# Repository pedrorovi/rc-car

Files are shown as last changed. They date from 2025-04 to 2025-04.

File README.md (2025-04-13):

# RC Car Project

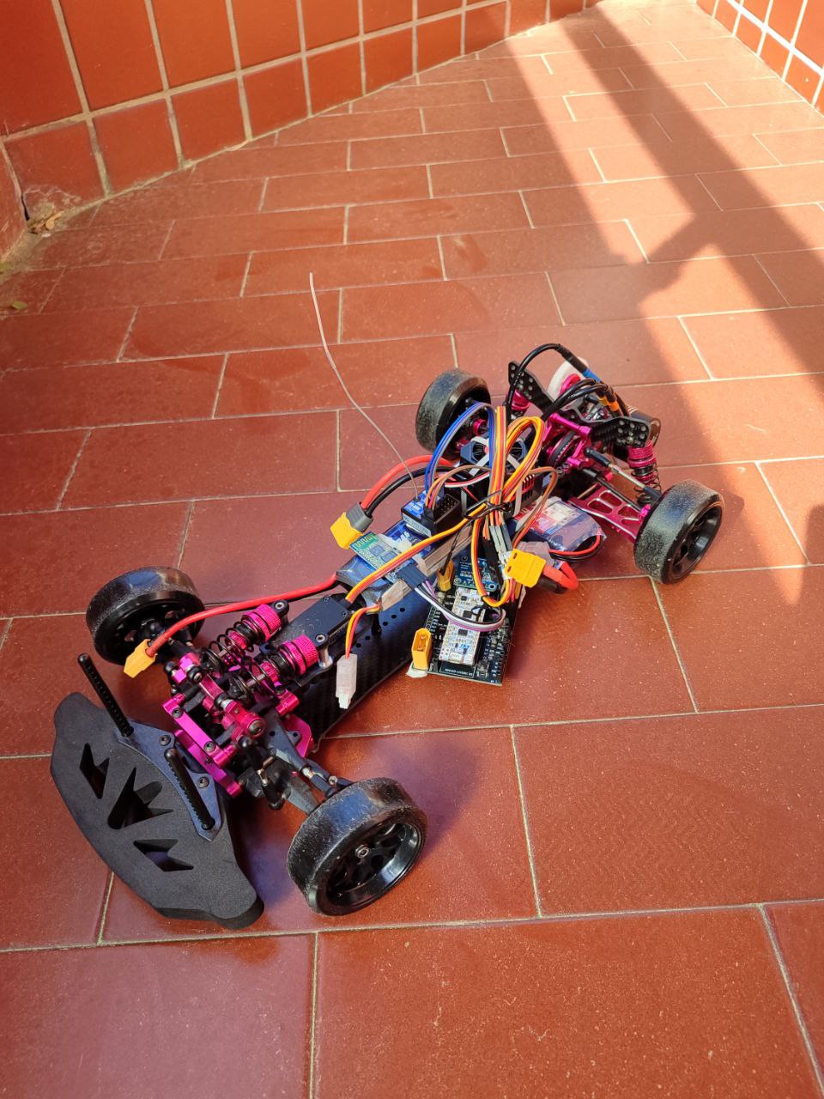
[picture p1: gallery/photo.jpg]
RC Car

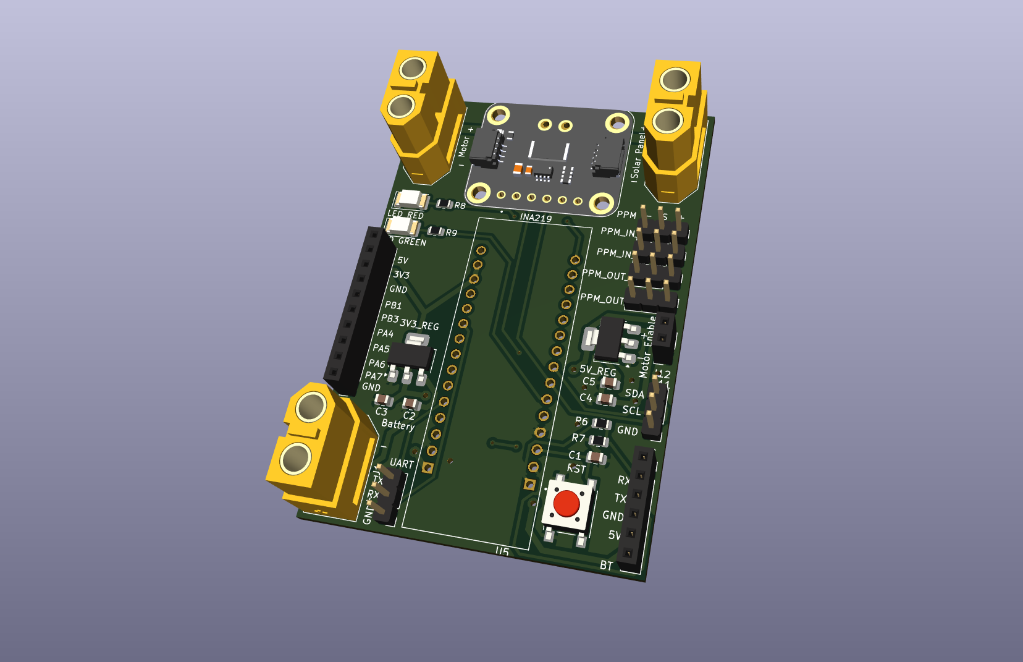
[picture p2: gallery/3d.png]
PCB


This repository contains all the necessary files and resources to design, configure, and develop an RC car. The project is organized into three main folders:

## Folder Structure

### 1. `kicad/` - Hardware Design

This folder contains the hardware design files for the RC car, created using KiCad. It includes:

- PCB layout files (`.kicad_pcb`)
- Schematic files (`.kicad_sch`)
- Gerber files for manufacturing
- Drill files and reports

### 2. `stm32-cube-ide/` - STM32L432KC Configuration

This folder contains the configuration files for the STM32L432KC microcontroller, set up using STM32CubeIDE. It includes:

- Peripheral initialization
- Clock configuration
- Pin assignments

### 3. `platformio/` - Firmware Development

This folder contains the firmware source code for the RC car, developed using PlatformIO. It includes:

- Source code for motor control, sensors, and communication
- Configuration files for PlatformIO
- Unit tests for firmware components

## Getting Started

### Prerequisites

- [KiCad](https://kicad.org/) for hardware design
- [STM32CubeIDE](https://www.st.com/en/development-tools/stm32cubeide.html) for microcontroller configuration
- [PlatformIO](https://platformio.org/) for firmware development

### Steps to Build the RC Car

1. **Hardware Design**: Open the `kicad/` folder in KiCad to view and modify the PCB and schematic designs. Generate Gerber files for manufacturing.
2. **Microcontroller Configuration**: Open the `stm32-cube-ide/` folder in STM32CubeIDE to configure the STM32L432KC microcontroller.
3. **Firmware Development**: Use PlatformIO to write and upload firmware to the microcontroller. Navigate to the `platformio/` folder and run:

   ```sh
   make build_embedded

## Shopping list

### Nucleo

[STM32L432KC](https://www.digikey.es/es/products/detail/stmicroelectronics/NUCLEO-L432KC/6132763)

### Radio

[Goolsky Flysky FS-GT5 2.4G 6CH Transmitter Remote Controller with FS-BS6 Receiver for RC Car Crawler Boat](https://a.co/d/gxiTpZ9)

### Car

[AXSPEED-Kit](https://es.aliexpress.com/item/1005004083219971.html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)

### Motor

[Rocket-Motor](https://es.aliexpress.com/item/1005003152797506.html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)

### Servo

[INJORA-Servo Digital](https://es.aliexpress.com/item/1005005066982557.html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)

### Batteries

[Zeee 2S Lipo Batería 50C 2200mAh 7.4V Batería Corta con Enchufe XT60](https://amzn.eu/d/79buMsG)

[Motor Battery](https://es.aliexpress.com/item/1005004770752418.html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)

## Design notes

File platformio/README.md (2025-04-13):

# RC Solar Car - STM32L432KC

This project is an embedded software application for controlling an RC solar-powered car using the STM32L432KC microcontroller. It includes various modules for hardware abstraction, motor control, power monitoring, and communication.

## Project Structure

. ├── .clang-format # Code formatting configuration ├── .gitignore # Git ignore rules ├── Makefile # Build system configuration ├── platformio.ini # PlatformIO project configuration ├── include/ # Header files for the project ├── lib/ # Libraries for hardware abstraction and drivers │ ├── FreeRTOS/ # FreeRTOS kernel source │ ├── hal/ # Hardware Abstraction Layer │ ├── motor_controller/ # Motor control logic │ ├── ina219/ # INA219 power sensor driver │ ├── debug/ # Debugging utilities │ └── ... # Other libraries ├── src/ # Application source code │ └── main.cpp # Main application entry point ├── test/ # Unit tests for the project └── README.md # Project documentation

## Features

- **Motor Control**: Includes modules for controlling DC and servo motors.
- **Power Monitoring**: Uses the INA219 sensor to measure current and voltage.
- **FreeRTOS Integration**: Real-time operating system for task scheduling.
- **Debugging Utilities**: Provides logging and debugging support.
- **Hardware Abstraction**: Simplifies interaction with peripherals like GPIO, I2C, and UART.

## Getting Started

### Prerequisites

- [PlatformIO](https://platformio.org/) installed on your system.
- STM32L432KC microcontroller development board.
- INA219 power sensor module.
- Motor drivers and motors.

### Building the Project

1. Build the project using PlatformIO:

```bash
make build_embedded
```

Upload the firmware to the STM32L432KC board:

```bash
make flash_embedded
```

Running Unit Tests
To run unit tests, use the PlatformIO Test Runner:

```bash
make test_*
```

License
This project includes components licensed under various open-source licenses:

The STM32 HAL driver is licensed under the BSD 3-Clause License.
The CMSIS library is licensed under the Apache License 2.0.
FreeRTOS is licensed under the MIT License.
Refer to the respective License.md files in the project for more details.

Contributing
Contributions are welcome! Please follow the coding style defined in the .clang-format file and ensure all tests pass before submitting a pull request.

Acknowledgments
STMicroelectronics for the STM32 HAL and CMSIS libraries.
Adafruit for the INA219 driver.
PlatformIO for the development environment.
For more information, refer to the documentation in the source code and the PlatformIO documentation. ```

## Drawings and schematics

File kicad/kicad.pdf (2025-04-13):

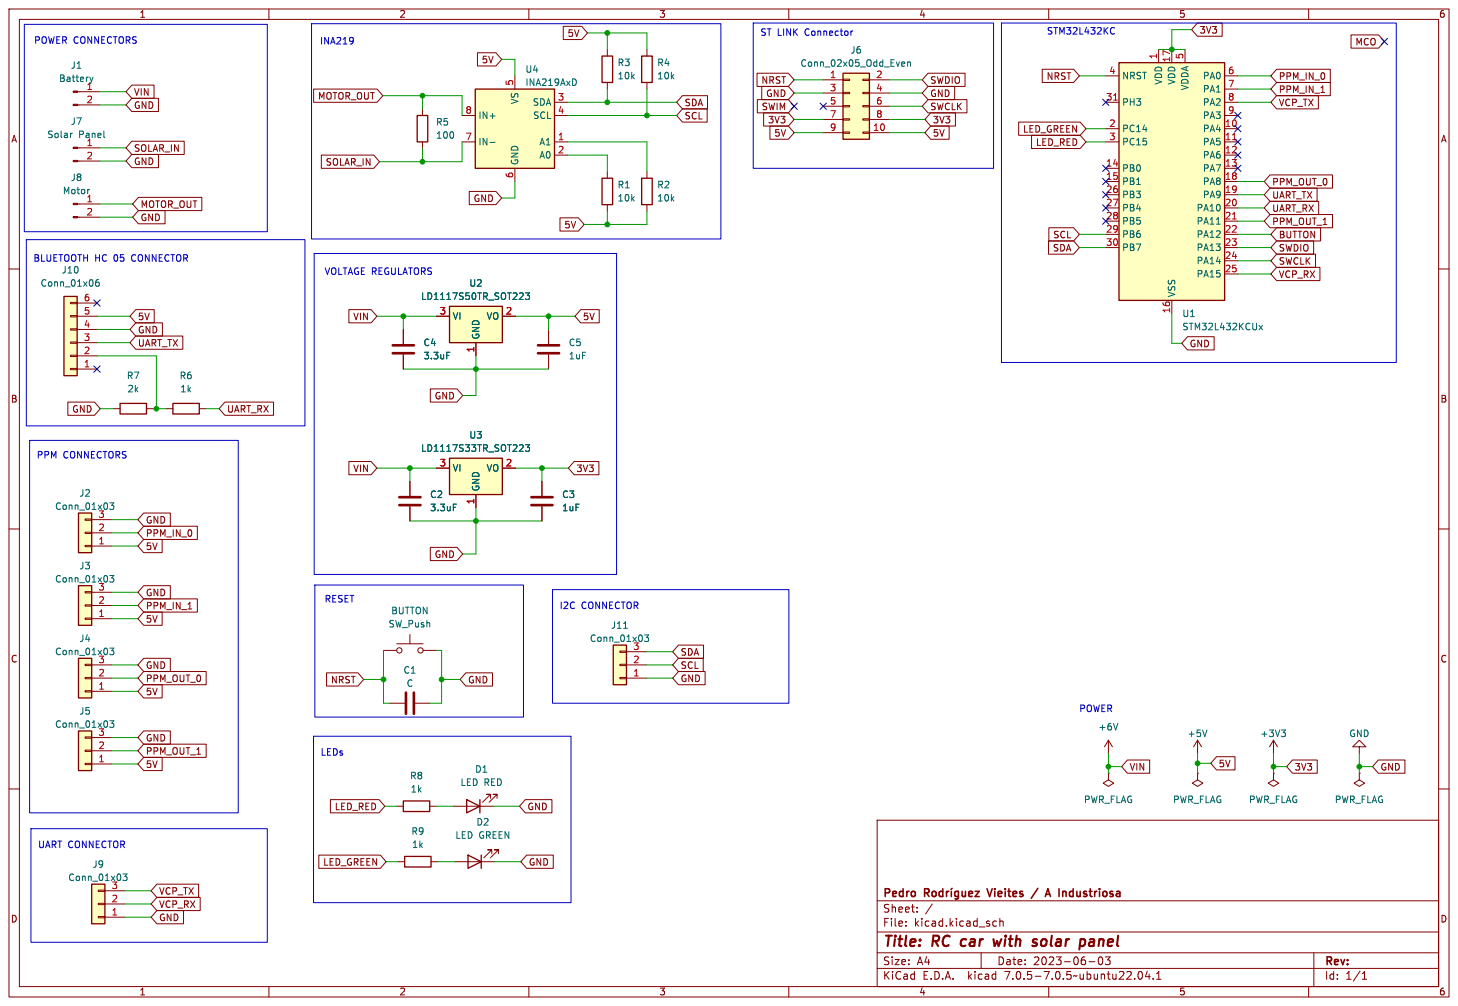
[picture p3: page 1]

1 PA4 10 PA5 11 PA6 12 PA7 13 PB0 14 PB1 15 VSS 16 VDD 17 PA8 18 PA9 19 PC14 2 PA10 20 PA11 21 PA12 22 PA13 23 PA14 24 PA15 25 PB3 26 PB4 27 PB5 28 PB6 29 PC15 3 PB7 30 PH3 31 NRST 4 VDDA

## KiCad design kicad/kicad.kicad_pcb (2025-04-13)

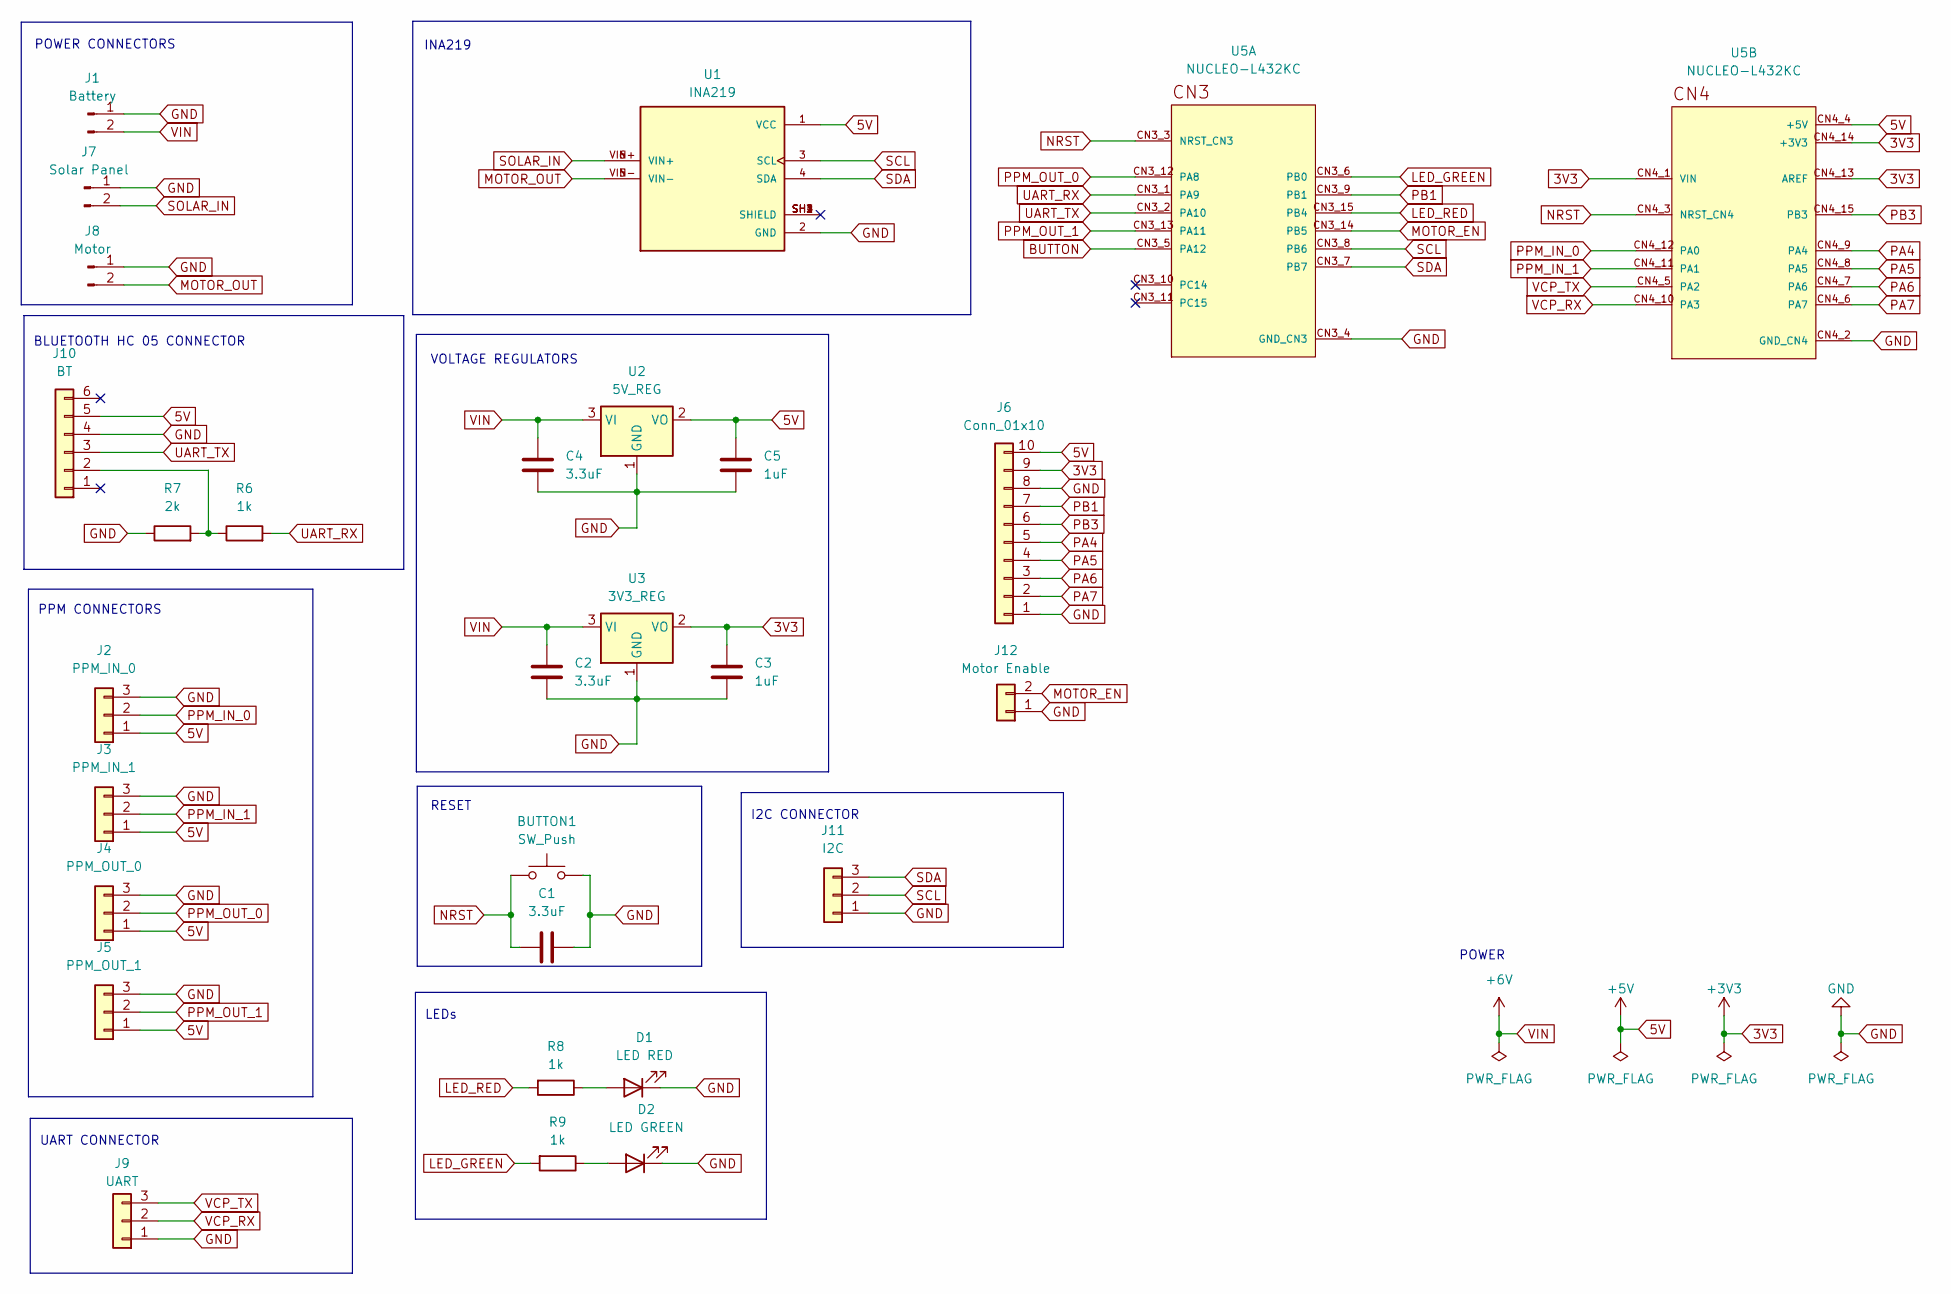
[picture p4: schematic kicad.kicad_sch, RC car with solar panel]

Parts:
BUTTON1: SW_Push; SW_SPST_PTS645
C1, C2, C4: 3.3uF; C_0805_2012Metric
C3, C5: 1uF; C_0805_2012Metric
D1: LED RED; LED_2010_5025Metric
D2: LED GREEN; LED_2010_5025Metric
J1: Battery; AMASS_XT60-F_1x02_P7.20mm_Vertical
J2: PPM_IN_0; PinHeader_1x03_P2.54mm_Vertical
J3: PPM_IN_1; PinHeader_1x03_P2.54mm_Vertical
J4: PPM_OUT_0; PinHeader_1x03_P2.54mm_Vertical
J5: PPM_OUT_1; PinHeader_1x03_P2.54mm_Vertical
J6: Conn_01x10; PinSocket_1x10_P2.54mm_Vertical
J7: Solar Panel; AMASS_XT60-F_1x02_P7.20mm_Vertical
J8: Motor; AMASS_XT60-F_1x02_P7.20mm_Vertical
J9: UART; PinHeader_1x03_P2.54mm_Vertical
J10: BT; PinSocket_1x06_P2.54mm_Vertical
J11: I2C; PinHeader_1x03_P2.54mm_Vertical
J12: Motor Enable; PinSocket_1x02_P2.54mm_Vertical
R6, R8, R9: 1k; R_0805_2012Metric
R7: 2k; R_0805_2012Metric
U1: INA219; MODULE_904; PARTREV C
U2: 5V_REG; SOT-223-3_TabPin2
U3: 3V3_REG; SOT-223-3_TabPin2
U5: NUCLEO-L432KC; MODULE_NUCLEO-L432KC; PARTREV N/A

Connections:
3V3: C3.1, J6.9, U3.2 (VO), U5.CN4_1 (VIN), U5.CN4_13 (AREF), U5.CN4_14 (+3V3)
5V: C5.1, J2.1, J3.1, J4.1, J5.1, J6.10, J10.5, U1.1 (VCC), U2.2 (VO), U5.CN4_4 (+5V)
BUTTON: U5.CN3_5 (PA12)
GND: BUTTON1.2, C1.1, C2.2, C3.2, C4.2, C5.2, D1.1 (K), D2.1 (K), J1.1, J2.3, J3.3, J4.3, J5.3, J6.1, J6.8, J7.1, J8.1, J9.1, J10.4, J11.1, J12.1, R7.1, U1.2 (GND), U2.1 (GND), U3.1 (GND), U5.CN3_4 (GND_CN3), U5.CN4_2 (GND_CN4)
LED_GREEN: R9.2, U5.CN3_6 (PB0)
LED_RED: R8.2, U5.CN3_15 (PB4)
MOTOR_EN: J12.2, U5.CN3_14 (PB5)
MOTOR_OUT: J8.2, U1.5 (VIN-), U1.VIN-
NRST: BUTTON1.1, C1.2, U5.CN3_3 (NRST_CN3), U5.CN4_3 (NRST_CN4)
unnamed: D1.2 (A), R8.1
unnamed: D2.2 (A), R9.1
unnamed: J10.2, R6.1, R7.2
PA4: J6.5, U5.CN4_9 (PA4)
PA5: J6.4, U5.CN4_8 (PA5)
PA6: J6.3, U5.CN4_7 (PA6)
PA7: J6.2, U5.CN4_6 (PA7)
PB1: J6.7, U5.CN3_9 (PB1)
PB3: J6.6, U5.CN4_15 (PB3)
PPM_IN_0: J2.2, U5.CN4_12 (PA0)
PPM_IN_1: J3.2, U5.CN4_11 (PA1)
PPM_OUT_0: J4.2, U5.CN3_12 (PA8)
PPM_OUT_1: J5.2, U5.CN3_13 (PA11)
SCL: J11.2, U1.3 (SCL), U5.CN3_8 (PB6)
SDA: J11.3, U1.4 (SDA), U5.CN3_7 (PB7)
SOLAR_IN: J7.2, U1.6 (VIN+), U1.VIN+
UART_RX: R6.2, U5.CN3_1 (PA9)
UART_TX: J10.3, U5.CN3_2 (PA10)
VCP_RX: J9.2, U5.CN4_10 (PA3)
VCP_TX: J9.3, U5.CN4_5 (PA2)
VIN: C2.1, C4.1, J1.2, U2.3 (VI), U3.3 (VI)

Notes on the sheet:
BLUETOOTH HC 05 CONNECTOR
POWER
PPM CONNECTORS
VOLTAGE REGULATORS
INA219
LEDs
UART CONNECTOR
I2C CONNECTOR
RESET
POWER CONNECTORS

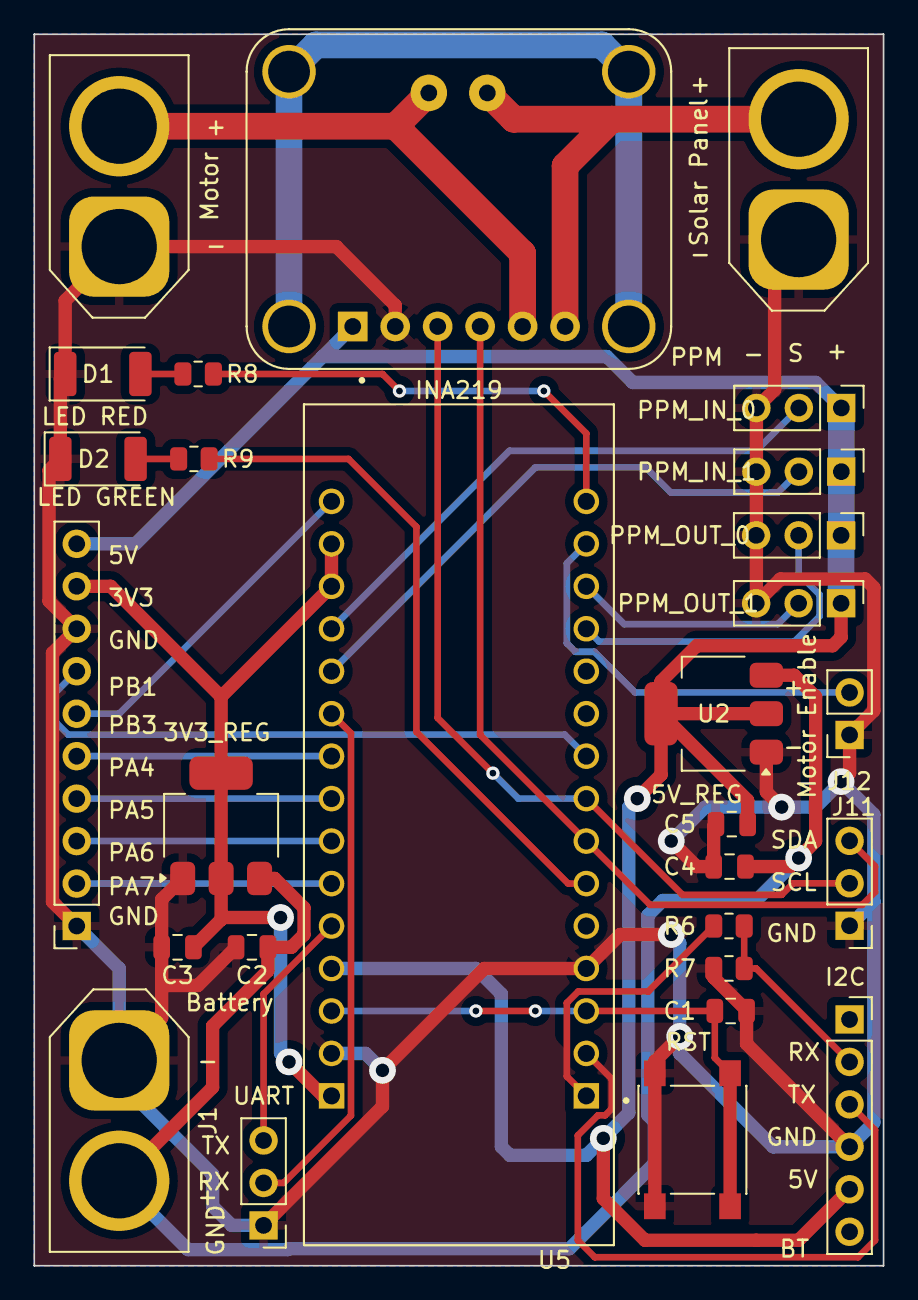
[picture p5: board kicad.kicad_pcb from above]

Board: 2 copper layers, 50.8 x 73.7 mm, 28 parts (0 on the bottom side), 29 nets.

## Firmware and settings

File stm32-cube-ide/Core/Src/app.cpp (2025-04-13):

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
/* Includes ------------------------------------------------------------------*/
#include "main.h"

I2C_HandleTypeDef hi2c1;

TIM_HandleTypeDef htim1;
TIM_HandleTypeDef htim2;
TIM_HandleTypeDef htim15;

UART_HandleTypeDef huart1;
UART_HandleTypeDef huart2;

void SystemClock_Config(void);
static void MX_GPIO_Init(void);
static void MX_USART2_UART_Init(void);
static void MX_I2C1_Init(void);
static void MX_TIM1_Init(void);
static void MX_TIM2_Init(void);
static void MX_USART1_UART_Init(void);
static void MX_TIM15_Init(void);
/* USER CODE BEGIN 0 */

#define TIMCLOCK 32000000
#define PRESCALAR 1

uint32_t tim2_ch1_IC_Val1 = 0;
uint32_t tim2_ch2_IC_Val1 = 0;
uint32_t tim2_ch1_IC_Val2 = 0;
uint32_t tim2_ch2_IC_Val2 = 0;
float tim2_ch1_Difference = 0;
float tim2_ch2_Difference = 0;
int tim2_ch1_Is_First_Captured = 0;
int tim2_ch2_Is_First_Captured = 0;

/* Measure Frequency */
float tim2_ch1_frequency = 0;
float tim2_ch2_frequency = 0;
/*
void HAL_TIM_IC_CaptureCallback(TIM_HandleTypeDef *htim)
{
        if (htim->Channel == HAL_TIM_ACTIVE_CHANNEL_1)
        {
                if (tim2_ch1_Is_First_Captured==0) // if the first rising edge
is not captured
                {
                        tim2_ch1_IC_Val1 = HAL_TIM_ReadCapturedValue(htim,
TIM_CHANNEL_1); // read the first value tim2_ch1_Is_First_Captured = 1;  // set
the first captured as true
                }

                else   // If the first rising edge is captured, now we will
capture the second edge
                {
                        tim2_ch1_IC_Val2 = HAL_TIM_ReadCapturedValue(htim,
TIM_CHANNEL_1);  // read second value

                        if (tim2_ch1_IC_Val2 > tim2_ch1_IC_Val1)
                        {
                                tim2_ch1_Difference =
tim2_ch1_IC_Val2-tim2_ch1_IC_Val1;
                        }

                        else if (tim2_ch1_IC_Val1 > tim2_ch1_IC_Val2)
                        {
                                tim2_ch1_Difference = (0xffffffff -
tim2_ch1_IC_Val1) + tim2_ch1_IC_Val2;
                        }

                        float refClock = TIMCLOCK/(PRESCALAR);

                        tim2_ch1_frequency = refClock/tim2_ch1_Difference;

                        __HAL_TIM_SET_COUNTER(htim, 0);  // reset the counter
                        tim2_ch1_Is_First_Captured = 0; // set it back to false
                }
        }
}

*/
/* Measure Width */
float tim2_ch1_usWidth = 0;
float tim2_ch2_usWidth = 0;

void HAL_TIM_IC_CaptureCallback(TIM_HandleTypeDef *htim) {
  if (htim->Channel ==
      HAL_TIM_ACTIVE_CHANNEL_1) // if the interrupt source is channel1
  {
    if (tim2_ch1_Is_First_Captured == 0) // if the first value is not captured
    {
      tim2_ch1_IC_Val1 = HAL_TIM_ReadCapturedValue(
          htim, TIM_CHANNEL_1);       // read the first value
      tim2_ch1_Is_First_Captured = 1; // set the first captured as true
    }

    else // if the first is already captured
    {
      tim2_ch1_IC_Val2 =
          HAL_TIM_ReadCapturedValue(htim, TIM_CHANNEL_1); // read second value

      if (tim2_ch1_IC_Val2 > tim2_ch1_IC_Val1) {
        tim2_ch1_Difference = tim2_ch1_IC_Val2 - tim2_ch1_IC_Val1;
      }

      else if (tim2_ch1_IC_Val1 > tim2_ch1_IC_Val2) {
        tim2_ch1_Difference =
            (0xffffffff - tim2_ch1_IC_Val1) + tim2_ch1_IC_Val2;
      }

      float refClock = TIMCLOCK / (PRESCALAR);
      float mFactor = 1000000 / refClock;

      tim2_ch1_usWidth = tim2_ch1_Difference * mFactor;
      // __HAL_TIM_SET_COUNTER(htim, 0);  // reset the counter
      TIM1->CCR1 = tim2_ch1_usWidth;
      tim2_ch1_Is_First_Captured = 0; // set it back to false
    }
  } else if (htim->Channel == HAL_TIM_ACTIVE_CHANNEL_2) {
    if (tim2_ch2_Is_First_Captured == 0) // if the first value is not captured
    {
      tim2_ch2_IC_Val1 = HAL_TIM_ReadCapturedValue(
          htim, TIM_CHANNEL_2);       // read the first value
      tim2_ch2_Is_First_Captured = 1; // set the first captured as true
    } else                            // if the first is already captured
    {
      tim2_ch2_IC_Val2 =
          HAL_TIM_ReadCapturedValue(htim, TIM_CHANNEL_2); // read second value
      if (tim2_ch2_IC_Val2 > tim2_ch2_IC_Val1) {
        tim2_ch2_Difference = tim2_ch2_IC_Val2 - tim2_ch2_IC_Val1;
      } else if (tim2_ch2_IC_Val1 > tim2_ch2_IC_Val2) {
        tim2_ch2_Difference =
            (0xffffffff - tim2_ch2_IC_Val1) + tim2_ch2_IC_Val2;
      }

      float refClock = TIMCLOCK / (PRESCALAR);
      float mFactor = 1000000 / refClock;

      tim2_ch2_usWidth = tim2_ch2_Difference * mFactor;

      TIM1->CCR4 = tim2_ch2_usWidth;

      // __HAL_TIM_SET_COUNTER(htim, 0);  // reset the counter
      tim2_ch2_Is_First_Captured = 0; // set it back to false
    }
  }
}

/* USER CODE END 0 */

/**
 * @brief  The application entry point.
 * @retval int
 */
int main(void) {
  /* MCU Configuration--------------------------------------------------------*/

  /* Reset of all peripherals, Initializes the Flash interface and the Systick.
   */
  HAL_Init();

  /* Configure the system clock */
  SystemClock_Config();

  /* Initialize all configured peripherals */
  MX_GPIO_Init();
  MX_USART2_UART_Init();
  MX_I2C1_Init();
  MX_TIM1_Init();
  MX_TIM2_Init();
  MX_USART1_UART_Init();
  MX_TIM15_Init();
  /* USER CODE BEGIN 2 */

  // TIM1->CCR1 = 1500;
  // TIM1->CCR4 = 1250;

  HAL_TIM_PWM_Start(&htim1, TIM_CHANNEL_1);
  HAL_TIM_PWM_Start(&htim1, TIM_CHANNEL_4);

  HAL_TIM_IC_Start_IT(&htim2, TIM_CHANNEL_1);
  HAL_TIM_IC_Start_IT(&htim2, TIM_CHANNEL_2);

  HAL_GPIO_WritePin(D7_GPIO_Port, D7_Pin, GPIO_PIN_SET);

  /* USER CODE END 2 */

  /* Infinite loop */
  /* USER CODE BEGIN WHILE */
  while (1) {
    /* USER CODE END WHILE */
    bool button = HAL_GPIO_ReadPin(D2_GPIO_Port, D2_Pin);
    if (button == false) {
      HAL_GPIO_WritePin(D7_GPIO_Port, D7_Pin, GPIO_PIN_RESET);
      // break;
    } else {
      HAL_GPIO_TogglePin(D7_GPIO_Port, D7_Pin);
    }
    HAL_GPIO_TogglePin(D8_GPIO_Port, D8_Pin);
    HAL_Delay(100); /* Insert delay 100 ms */
    /* USER CODE BEGIN 3 */
  }
  /* USER CODE END 3 */
}

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


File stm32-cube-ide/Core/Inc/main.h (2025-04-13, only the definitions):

#define PPM_IN_0_Pin GPIO_PIN_0
#define PPM_IN_0_GPIO_Port GPIOA
#define PPM_IN_1_Pin GPIO_PIN_1
#define PPM_IN_1_GPIO_Port GPIOA
#define DEBUG_TX_Pin GPIO_PIN_2
#define DEBUG_TX_GPIO_Port GPIOA
#define DEBUG_RX_Pin GPIO_PIN_3
#define DEBUG_RX_GPIO_Port GPIOA
#define LED_RED_Pin GPIO_PIN_0
#define LED_RED_GPIO_Port GPIOB
#define PPM_OUT_0_Pin GPIO_PIN_8
#define PPM_OUT_0_GPIO_Port GPIOA
#define BT_TX_Pin GPIO_PIN_9
#define BT_TX_GPIO_Port GPIOA
#define BT_RX_Pin GPIO_PIN_10
#define BT_RX_GPIO_Port GPIOA
#define PPM_OUT_1_Pin GPIO_PIN_11
#define PPM_OUT_1_GPIO_Port GPIOA
#define LED_GREEN_Pin GPIO_PIN_4
#define LED_GREEN_GPIO_Port GPIOB
#define MOTOR_EN_Pin GPIO_PIN_5
#define MOTOR_EN_GPIO_Port GPIOB
#define SCL_Pin GPIO_PIN_6
#define SCL_GPIO_Port GPIOB
#define SDA_Pin GPIO_PIN_7
#define SDA_GPIO_Port GPIOB

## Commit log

2025-04-13 added kicad
    [kicad-B_Cu.gbr, kicad-B_Mask.gbr, kicad-B_Paste.gbr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]
2025-04-13 update shopping list with links to car model and motor battery
2025-04-13 add PCB image to README and include it in the gallery

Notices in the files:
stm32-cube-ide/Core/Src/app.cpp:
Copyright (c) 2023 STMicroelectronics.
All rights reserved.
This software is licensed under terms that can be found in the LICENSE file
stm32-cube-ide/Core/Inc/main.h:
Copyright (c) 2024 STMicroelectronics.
